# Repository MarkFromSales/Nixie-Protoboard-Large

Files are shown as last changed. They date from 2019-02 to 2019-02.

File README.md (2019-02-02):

# Nixie-Protoboard-Large Board
Protoboard for testing Nixie tube driving software development

I have a bunch of the new-old-stock K155ID1 chips that I found cheap on Amazon and eBay. I've been told NTE still makes the 74141 and found these links,

http://www.nteinc.com/specs/7400to7499/pdf/nte74141.pdf
http://dilp.netcomponents.com/cgi-bin/nteinc.asp?partnumber1=NTE74141

# Nixie Tube Tester Code
Learning to code for the Arduino for a Nixie tube project.
ATmega328 Driving SN74141 Nixie driver chip via pins A, B, C, & D

## Attributions and Thanks
- ATMega328 outside of Arduino Uno - https://dronebotworkshop.com/arduino-uno-atmega328/
- Multi-tasking the Arduino - https://learn.adafruit.com/multi-tasking-the-arduino-part-1?view=all

## Connections
```
ATMega328 Pin 28 (Analog 5 - I2C Clock) to MCP Pin 12
ATMega328 Pin 27 (Analog 4 - I2C Data)  to MCP Pin 13

MCP Pins #15, 16 and 17 are address selection (see below)
MCP Pin  9 to 5V
MCP Pin 10 to GND
MCP Pin 18 to 10K Resistor to 5V (reset pin, active low)
```

## MCP Addresses
```
addr 0 = A2 low,  A1 low,  A0 low  000
addr 1 = A2 low,  A1 low,  A0 high 001
addr 2 = A2 low,  A1 high, A0 low  010
addr 3 = A2 low,  A1 high, A0 high 011
addr 4 = A2 high, A1 low,  A0 low  100
addr 5 = A2 high, A1 low,  A0 high 101
addr 6 = A2 high, A1 high, A0 low  110
addr 7 = A2 high, A1 high, A0 high 111
```

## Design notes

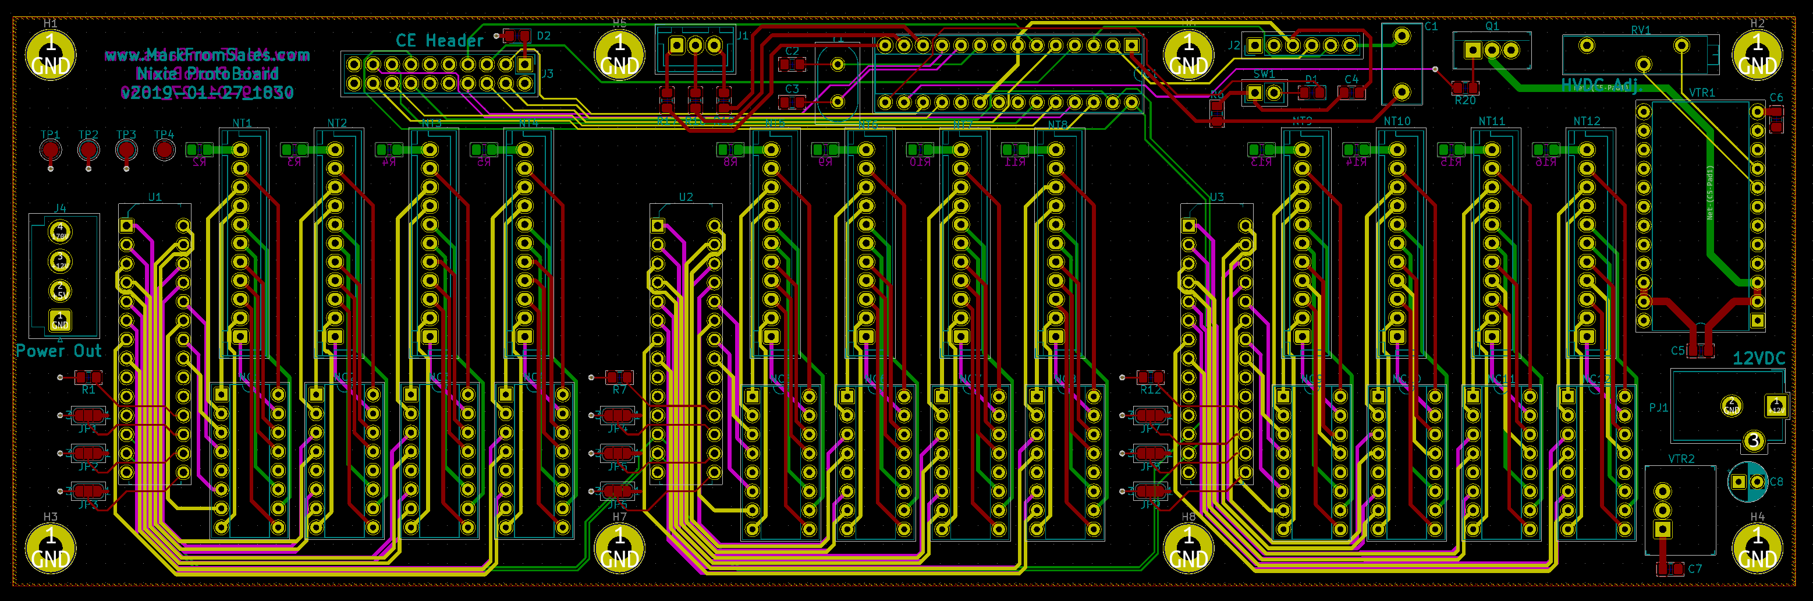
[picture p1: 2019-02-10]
Nixie-Protoboard-Large_PCB_Screenshot.PNG

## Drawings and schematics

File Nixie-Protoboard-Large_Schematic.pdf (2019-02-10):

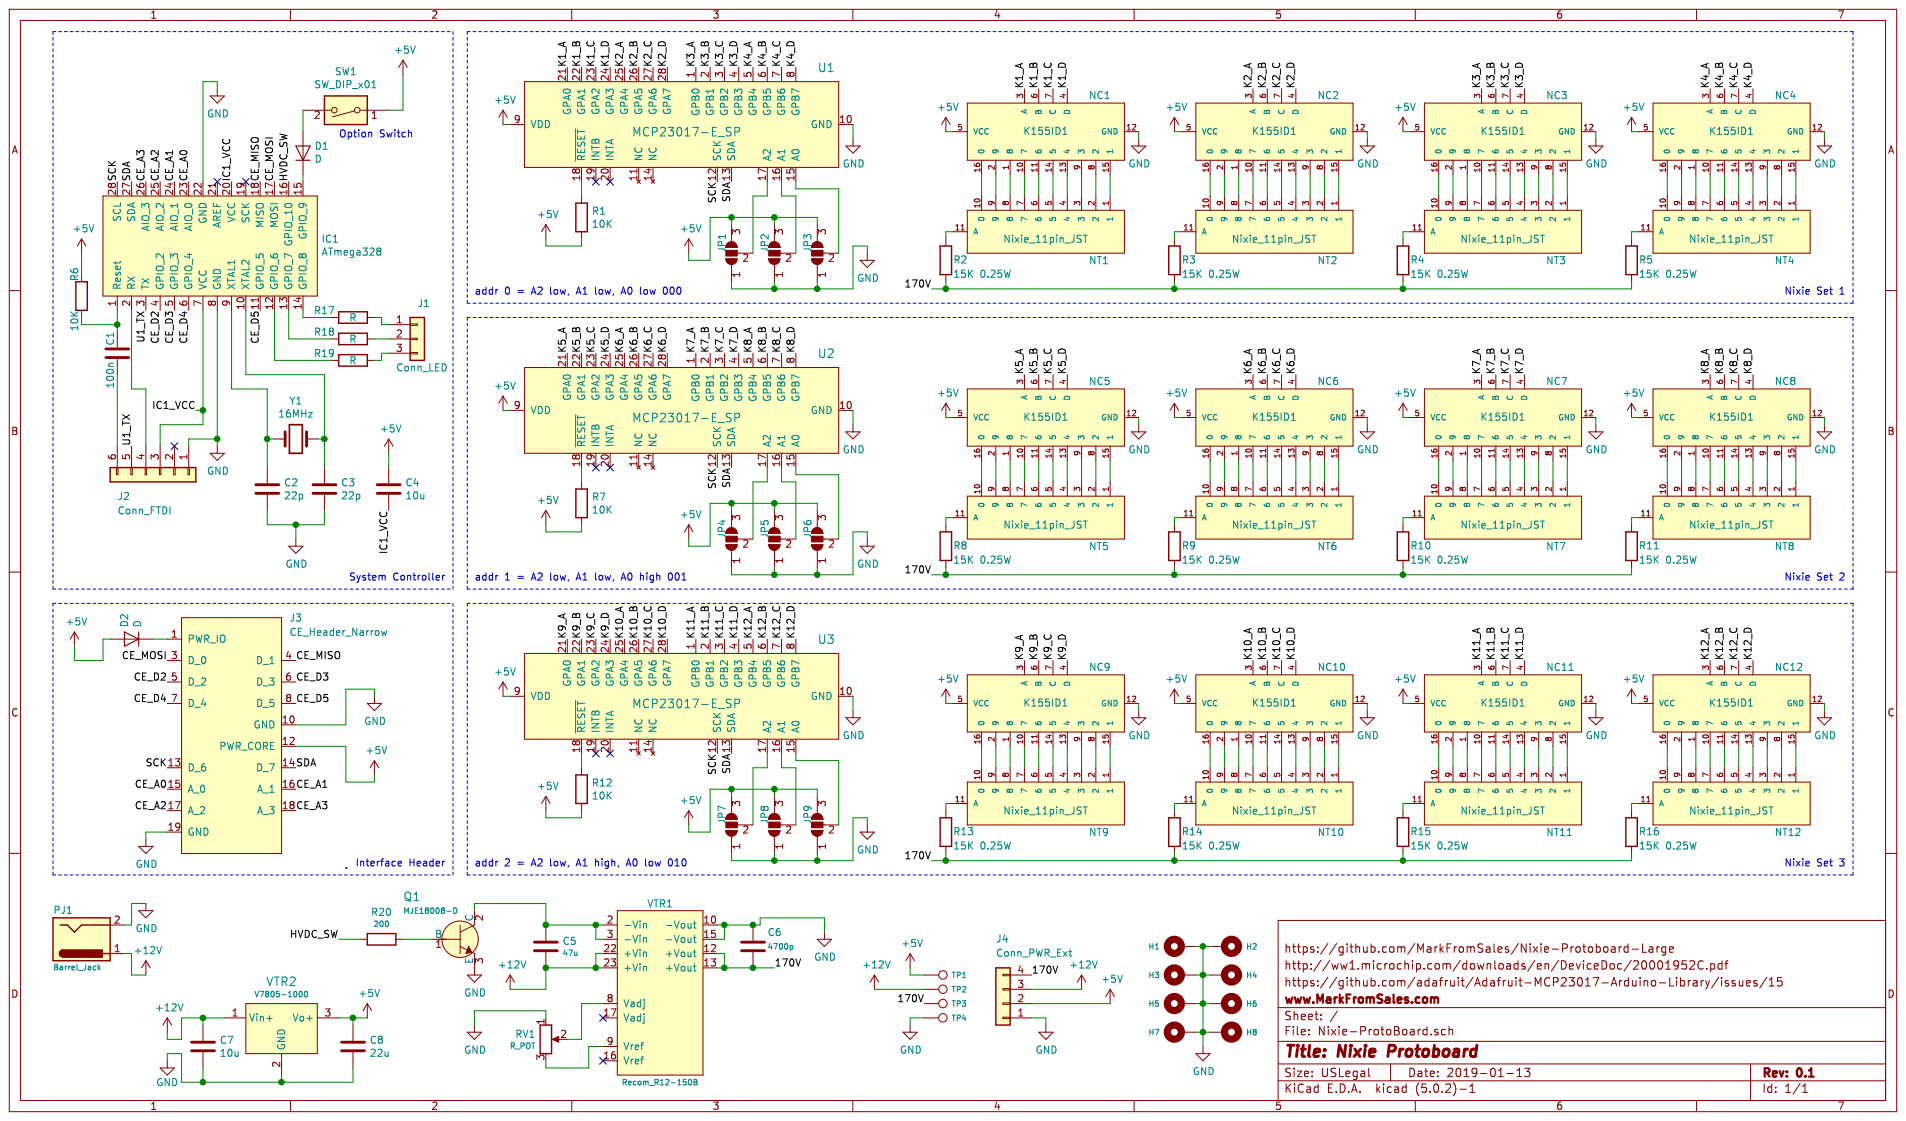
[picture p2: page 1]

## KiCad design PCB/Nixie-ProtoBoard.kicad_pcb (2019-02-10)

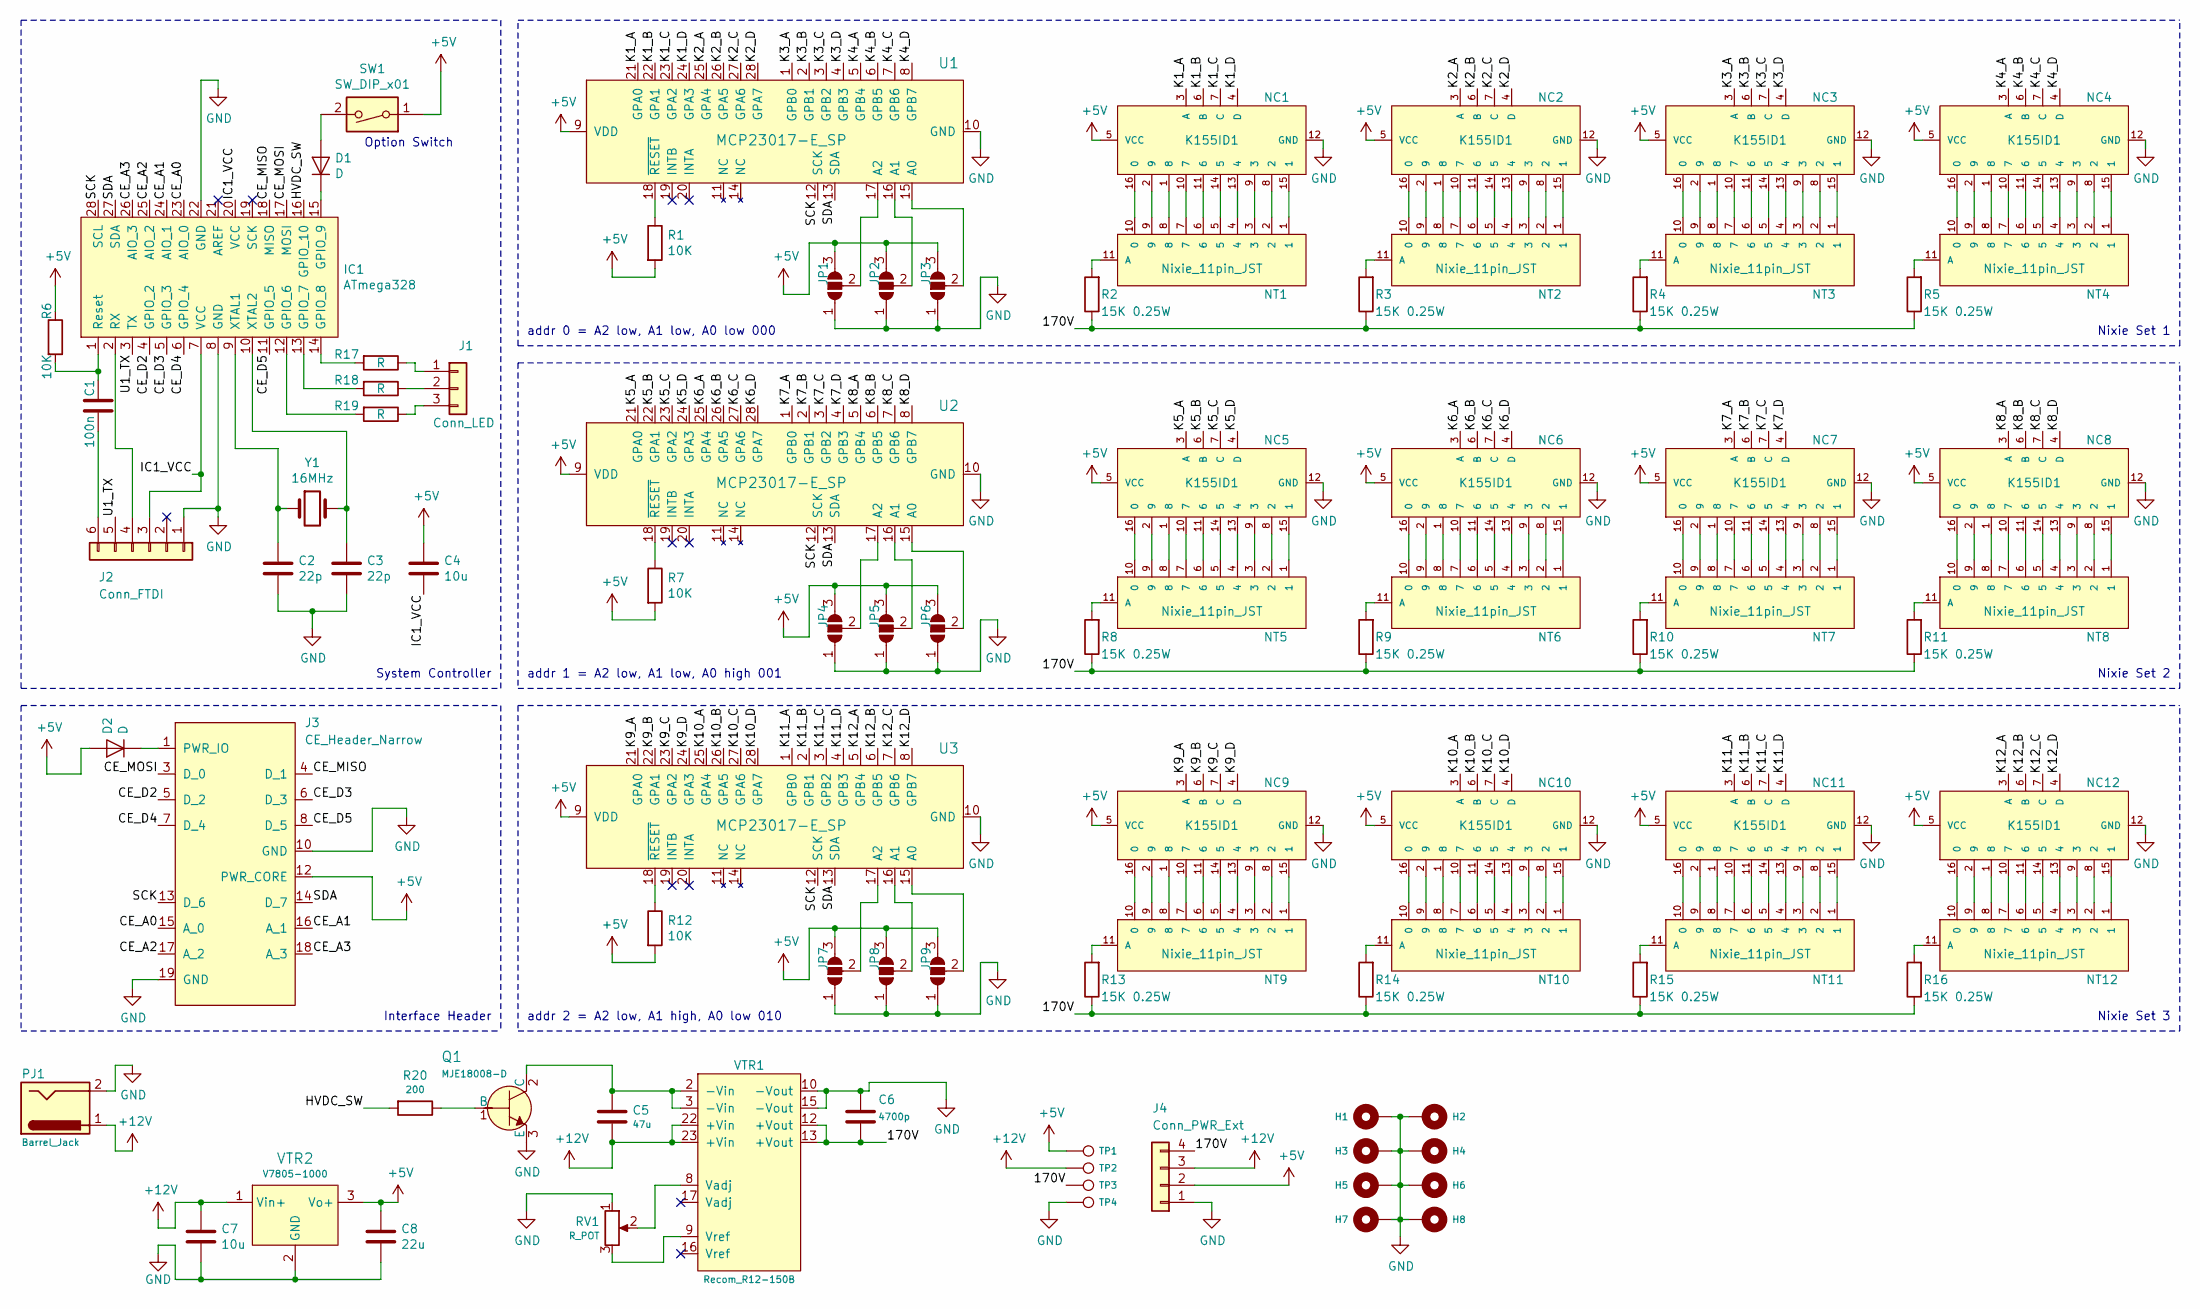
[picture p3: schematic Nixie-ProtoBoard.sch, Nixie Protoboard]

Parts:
C1: 100n; C_Disc_D10.5mm_W5.0mm_P7.50mm
C2, C3: 22p; C_0805_2012Metric_Pad1.15x1.40mm_HandSolder
C4, C7: 10u; C_0805_2012Metric_Pad1.15x1.40mm_HandSolder
C5: 47u; C_0805_2012Metric_Pad1.15x1.40mm_HandSolder
C6: 4700p; C_0805_2012Metric_Pad1.15x1.40mm_HandSolder
C8: 22u; CP_Radial_D5.0mm_P2.50mm
D1, D2: D; D_0805_2012Metric_Pad1.15x1.40mm_HandSolder
H1, H2, H3, H4, H5, H6, H7, H8: MountingHole_Pad; MountingHole_3.2mm_M3_Pad
IC1: ATmega328; DIP-28_W7.62mm_Socket
J1: Conn_LED; JST_XH_B03B-XH-A_1x03_P2.50mm_Vertical
J2: Conn_FTDI; PinHeader_1x06_P2.54mm_Vertical
J3: CE_Header_Narrow; PinHeader_2x10_P2.54mm_Vertical
J4: Conn_PWR_Ext; JST_VH_B4P-VH_1x04_P3.96mm_Vertical
JP1, JP2, JP3, JP4, JP5, JP6, JP7, JP8, JP9: SolderJumper_3_Open; SolderJumper-3_P1.3mm_Open_RoundedPad1.0x1.5mm_NumberLabels
NC1, NC2, NC3, NC4, NC5, NC6, NC7, NC8, NC9, NC10, NC11, NC12: K155ID1; DIP-16_W7.62mm_Socket
NT1, NT2, NT3, NT4, NT5, NT6, NT7, NT8, NT9, NT10, NT11, NT12: Nixie_11pin_JST; JST_XH_B11B-XH-A_1x11_P2.50mm_Vertical
PJ1: Barrel_Jack; BarrelJack_CUI_PJ-102AH_Horizontal
Q1: MJE18008-D; TO-220-3; MPN MJE15030G; Digi-Key_PN MJE15030GOS-ND
R1, R6, R7, R12: 10K; R_0805_2012Metric_Pad1.15x1.40mm_HandSolder
R2, R3, R4, R5, R8, R9, R10, R11, R13, R14, R15, R16: 15K 0.25W; R_0805_2012Metric_Pad1.15x1.40mm_HandSolder
R17, R18, R19: R; R_0805_2012Metric_Pad1.15x1.40mm_HandSolder
R20: 200; R_0805_2012Metric_Pad1.15x1.40mm_HandSolder
RV1: R_POT; Potentiometer_Vishay_43_Horizontal
SW1: SW_DIP_x01; PinHeader_1x02_P2.54mm_Vertical
TP1, TP2, TP3, TP4: TestPoint; TestPoint_Pad_D2.0mm
U1, U2, U3: MCP23017-E_SP; DIP-28_W7.62mm; MPN MCP23017-E/SP; Digi-Key_PN MCP23017-E/SP-ND
VTR1: Recom_R12-150B; DIP-24_W15.24mm
VTR2: V7805-1000; 3-SIP_Module_V7805-1000; MPN V7805-1000; Digi-Key_PN 102-1715-ND
Y1: 16MHz; Resonator-2Pin_W10.0mm_H5.0mm

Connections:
+5V: C4.1, C8.1, D2.2 (A), J3.12 (PWR_CORE), J4.2, JP1.3 (B), JP2.3 (B), JP3.3 (B), JP4.3 (B), JP5.3 (B), JP6.3 (B), JP7.3 (B), JP8.3 (B), JP9.3 (B), NC1.5 (VCC), NC2.5 (VCC), NC3.5 (VCC), NC4.5 (VCC), NC5.5 (VCC), NC6.5 (VCC), NC7.5 (VCC), NC8.5 (VCC), NC9.5 (VCC), NC10.5 (VCC), NC11.5 (VCC), NC12.5 (VCC), R1.2, R6.1, R7.2, R12.2, SW1.1, TP1.1, U1.9 (VDD), U2.9 (VDD), U3.9 (VDD), VTR2.3 (Vo+)
+12V: C5.2, C7.1, J4.3, PJ1.1, TP2.1, VTR1.22 (+Vin), VTR1.23 (+Vin), VTR2.1 (Vin+)
/170V: C6.2, J4.4, R2.1, R3.1, R4.1, R5.1, R8.1, R9.1, R10.1, R11.1, R13.1, R14.1, R15.1, R16.1, TP3.1, VTR1.12 (+Vout), VTR1.13 (+Vout)
/CE_A0: IC1.23 (AIO_0), J3.15 (A_0)
/CE_A1: IC1.24 (AIO_1), J3.16 (A_1)
/CE_A2: IC1.25 (AIO_2), J3.17 (A_2)
/CE_A3: IC1.26 (AIO_3), J3.18 (A_3)
/CE_D2: IC1.4 (GPIO_2), J3.5 (D_2)
/CE_D3: IC1.5 (GPIO_3), J3.6 (D_3)
/CE_D4: IC1.6 (GPIO_4), J3.7 (D_4)
/CE_D5: IC1.11 (GPIO_5), J3.8 (D_5)
/CE_MISO: IC1.18 (MISO), J3.4 (D_1)
/CE_MOSI: IC1.17 (MOSI), J3.3 (D_0)
/HVDC_SW: IC1.16 (GPIO_10), R20.2
/IC1_VCC: C4.2, IC1.7 (VCC), IC1.20 (VCC), J2.3
/K1_A: NC1.3 (A), U1.21 (GPA0)
/K1_B: NC1.6 (B), U1.22 (GPA1)
/K1_C: NC1.7 (C), U1.23 (GPA2)
/K1_D: NC1.4 (D), U1.24 (GPA3)
/K2_A: NC2.3 (A), U1.25 (GPA4)
/K2_B: NC2.6 (B), U1.26 (GPA5)
/K2_C: NC2.7 (C), U1.27 (GPA6)
/K2_D: NC2.4 (D), U1.28 (GPA7)
/K3_A: NC3.3 (A), U1.1 (GPB0)
/K3_B: NC3.6 (B), U1.2 (GPB1)
/K3_C: NC3.7 (C), U1.3 (GPB2)
/K3_D: NC3.4 (D), U1.4 (GPB3)
/K4_A: NC4.3 (A), U1.5 (GPB4)
/K4_B: NC4.6 (B), U1.6 (GPB5)
/K4_C: NC4.7 (C), U1.7 (GPB6)
/K4_D: NC4.4 (D), U1.8 (GPB7)
/K5_A: NC5.3 (A), U2.21 (GPA0)
/K5_B: NC5.6 (B), U2.22 (GPA1)
/K5_C: NC5.7 (C), U2.23 (GPA2)
/K5_D: NC5.4 (D), U2.24 (GPA3)
/K6_A: NC6.3 (A), U2.25 (GPA4)
/K6_B: NC6.6 (B), U2.26 (GPA5)
/K6_C: NC6.7 (C), U2.27 (GPA6)
/K6_D: NC6.4 (D), U2.28 (GPA7)
/K7_A: NC7.3 (A), U2.1 (GPB0)
/K7_B: NC7.6 (B), U2.2 (GPB1)
/K7_C: NC7.7 (C), U2.3 (GPB2)
/K7_D: NC7.4 (D), U2.4 (GPB3)
/K8_A: NC8.3 (A), U2.5 (GPB4)
/K8_B: NC8.6 (B), U2.6 (GPB5)
/K8_C: NC8.7 (C), U2.7 (GPB6)
/K8_D: NC8.4 (D), U2.8 (GPB7)
/K9_A: NC9.3 (A), U3.21 (GPA0)
/K9_B: NC9.6 (B), U3.22 (GPA1)
/K9_C: NC9.7 (C), U3.23 (GPA2)
/K9_D: NC9.4 (D), U3.24 (GPA3)
/K10_A: NC10.3 (A), U3.25 (GPA4)
/K10_B: NC10.6 (B), U3.26 (GPA5)
/K10_C: NC10.7 (C), U3.27 (GPA6)
/K10_D: NC10.4 (D), U3.28 (GPA7)
/K11_A: NC11.3 (A), U3.1 (GPB0)
/K11_B: NC11.6 (B), U3.2 (GPB1)
/K11_C: NC11.7 (C), U3.3 (GPB2)
/K11_D: NC11.4 (D), U3.4 (GPB3)
/K12_A: NC12.3 (A), U3.5 (GPB4)
/K12_B: NC12.6 (B), U3.6 (GPB5)
/K12_C: NC12.7 (C), U3.7 (GPB6)
/K12_D: NC12.4 (D), U3.8 (GPB7)
/SCK: IC1.28 (SCL), J3.13 (D_6), U1.12 (SCK), U2.12 (SCK), U3.12 (SCK)
/SDA: IC1.27 (SDA), J3.14 (D_7), U1.13 (SDA), U2.13 (SDA), U3.13 (SDA)
/U1_TX: IC1.3 (TX), J2.5
GND: C2.2, C3.2, C6.1, C7.2, C8.2, H1.1, H2.1, H3.1, H4.1, H5.1, H6.1, H7.1, H8.1, IC1.8 (GND), IC1.22 (GND), J2.1, J3.10 (GND), J3.19 (GND), J4.1, JP1.1 (A), JP2.1 (A), JP3.1 (A), JP4.1 (A), JP5.1 (A), JP6.1 (A), JP7.1 (A), JP8.1 (A), JP9.1 (A), NC1.12 (GND), NC2.12 (GND), NC3.12 (GND), NC4.12 (GND), NC5.12 (GND), NC6.12 (GND), NC7.12 (GND), NC8.12 (GND), NC9.12 (GND), NC10.12 (GND), NC11.12 (GND), NC12.12 (GND), PJ1.2, Q1.3 (E), RV1.1, TP4.1, U1.10 (GND), U2.10 (GND), U3.10 (GND), VTR1.10 (-Vout), VTR1.15 (-Vout), VTR2.2 (GND)
unnamed: C1.1, IC1.1 (Reset), R6.2
unnamed: C1.2, J2.6
unnamed: C2.1, IC1.9 (XTAL1), Y1.1
unnamed: C3.1, IC1.10 (XTAL2), Y1.2
unnamed: C5.1, Q1.2 (C), VTR1.2 (-Vin), VTR1.3 (-Vin)
unnamed: D1.1 (K), IC1.15 (GPIO_9)
unnamed: D1.2 (A), SW1.2
unnamed: D2.1 (K), J3.1 (PWR_IO)
unnamed: IC1.2 (RX), J2.4
unnamed: IC1.12 (GPIO_6), R19.2
unnamed: IC1.13 (GPIO_7), R18.2
unnamed: IC1.14 (GPIO_8), R17.2
unnamed: J1.1, R17.1
unnamed: J1.2, R18.1
unnamed: J1.3, R19.1
unnamed: JP1.2 (C), U1.17 (A2)
unnamed: JP2.2 (C), U1.16 (A1)
unnamed: JP3.2 (C), U1.15 (A0)
unnamed: JP4.2 (C), U2.17 (A2)
unnamed: JP5.2 (C), U2.16 (A1)
unnamed: JP6.2 (C), U2.15 (A0)
unnamed: JP7.2 (C), U3.17 (A2)
unnamed: JP8.2 (C), U3.16 (A1)
unnamed: JP9.2 (C), U3.15 (A0)
unnamed: NC1.1 (8), NT1.8
unnamed: NC1.2 (9), NT1.9
unnamed: NC1.8 (2), NT1.2
unnamed: NC1.9 (3), NT1.3
unnamed: NC1.10 (7), NT1.7
unnamed: NC1.11 (6), NT1.6
unnamed: NC1.13 (4), NT1.4
unnamed: NC1.14 (5), NT1.5
unnamed: NC1.15 (1), NT1.1
unnamed: NC1.16 (0), NT1.10 (0)
unnamed: NC2.1 (8), NT2.8
unnamed: NC2.2 (9), NT2.9
unnamed: NC2.8 (2), NT2.2
unnamed: NC2.9 (3), NT2.3
unnamed: NC2.10 (7), NT2.7
unnamed: NC2.11 (6), NT2.6
unnamed: NC2.13 (4), NT2.4
unnamed: NC2.14 (5), NT2.5
unnamed: NC2.15 (1), NT2.1
unnamed: NC2.16 (0), NT2.10 (0)
unnamed: NC3.1 (8), NT3.8
unnamed: NC3.2 (9), NT3.9
unnamed: NC3.8 (2), NT3.2
unnamed: NC3.9 (3), NT3.3
unnamed: NC3.10 (7), NT3.7
unnamed: NC3.11 (6), NT3.6
unnamed: NC3.13 (4), NT3.4
unnamed: NC3.14 (5), NT3.5
unnamed: NC3.15 (1), NT3.1
unnamed: NC3.16 (0), NT3.10 (0)
unnamed: NC4.1 (8), NT4.8
unnamed: NC4.2 (9), NT4.9
unnamed: NC4.8 (2), NT4.2
unnamed: NC4.9 (3), NT4.3
unnamed: NC4.10 (7), NT4.7
unnamed: NC4.11 (6), NT4.6
unnamed: NC4.13 (4), NT4.4
unnamed: NC4.14 (5), NT4.5
unnamed: NC4.15 (1), NT4.1
unnamed: NC4.16 (0), NT4.10 (0)
unnamed: NC5.1 (8), NT5.8
unnamed: NC5.2 (9), NT5.9
unnamed: NC5.8 (2), NT5.2
unnamed: NC5.9 (3), NT5.3
unnamed: NC5.10 (7), NT5.7
unnamed: NC5.11 (6), NT5.6
unnamed: NC5.13 (4), NT5.4
unnamed: NC5.14 (5), NT5.5
unnamed: NC5.15 (1), NT5.1
unnamed: NC5.16 (0), NT5.10 (0)
unnamed: NC6.1 (8), NT6.8
unnamed: NC6.2 (9), NT6.9
unnamed: NC6.8 (2), NT6.2
unnamed: NC6.9 (3), NT6.3
unnamed: NC6.10 (7), NT6.7
unnamed: NC6.11 (6), NT6.6
unnamed: NC6.13 (4), NT6.4
unnamed: NC6.14 (5), NT6.5
unnamed: NC6.15 (1), NT6.1
unnamed: NC6.16 (0), NT6.10 (0)
unnamed: NC7.1 (8), NT7.8
unnamed: NC7.2 (9), NT7.9
unnamed: NC7.8 (2), NT7.2
unnamed: NC7.9 (3), NT7.3
unnamed: NC7.10 (7), NT7.7
unnamed: NC7.11 (6), NT7.6
unnamed: NC7.13 (4), NT7.4
unnamed: NC7.14 (5), NT7.5
unnamed: NC7.15 (1), NT7.1
unnamed: NC7.16 (0), NT7.10 (0)
unnamed: NC8.1 (8), NT8.8
unnamed: NC8.2 (9), NT8.9
unnamed: NC8.8 (2), NT8.2
unnamed: NC8.9 (3), NT8.3
unnamed: NC8.10 (7), NT8.7
unnamed: NC8.11 (6), NT8.6
unnamed: NC8.13 (4), NT8.4
unnamed: NC8.14 (5), NT8.5
unnamed: NC8.15 (1), NT8.1
unnamed: NC8.16 (0), NT8.10 (0)
unnamed: NC9.1 (8), NT9.8
unnamed: NC9.2 (9), NT9.9
unnamed: NC9.8 (2), NT9.2
unnamed: NC9.9 (3), NT9.3
unnamed: NC9.10 (7), NT9.7
unnamed: NC9.11 (6), NT9.6
unnamed: NC9.13 (4), NT9.4
unnamed: NC9.14 (5), NT9.5
unnamed: NC9.15 (1), NT9.1
unnamed: NC9.16 (0), NT9.10 (0)
unnamed: NC10.1 (8), NT10.8
unnamed: NC10.2 (9), NT10.9
unnamed: NC10.8 (2), NT10.2
unnamed: NC10.9 (3), NT10.3
unnamed: NC10.10 (7), NT10.7
unnamed: NC10.11 (6), NT10.6
unnamed: NC10.13 (4), NT10.4
unnamed: NC10.14 (5), NT10.5
unnamed: NC10.15 (1), NT10.1
unnamed: NC10.16 (0), NT10.10 (0)
unnamed: NC11.1 (8), NT11.8
unnamed: NC11.2 (9), NT11.9
unnamed: NC11.8 (2), NT11.2
unnamed: NC11.9 (3), NT11.3
unnamed: NC11.10 (7), NT11.7
unnamed: NC11.11 (6), NT11.6
unnamed: NC11.13 (4), NT11.4
unnamed: NC11.14 (5), NT11.5
unnamed: NC11.15 (1), NT11.1
unnamed: NC11.16 (0), NT11.10 (0)
unnamed: NC12.1 (8), NT12.8
unnamed: NC12.2 (9), NT12.9
unnamed: NC12.8 (2), NT12.2
unnamed: NC12.9 (3), NT12.3
unnamed: NC12.10 (7), NT12.7
unnamed: NC12.11 (6), NT12.6
unnamed: NC12.13 (4), NT12.4
unnamed: NC12.14 (5), NT12.5
unnamed: NC12.15 (1), NT12.1
unnamed: NC12.16 (0), NT12.10 (0)
unnamed: NT1.11 (A), R2.2
unnamed: NT2.11 (A), R3.2
unnamed: NT3.11 (A), R4.2
unnamed: NT4.11 (A), R5.2
unnamed: NT5.11 (A), R8.2
unnamed: NT6.11 (A), R9.2
unnamed: NT7.11 (A), R10.2
unnamed: NT8.11 (A), R11.2
unnamed: NT9.11 (A), R13.2
unnamed: NT10.11 (A), R14.2
unnamed: NT11.11 (A), R15.2
unnamed: NT12.11 (A), R16.2
unnamed: Q1.1 (B), R20.1
unnamed: R1.1, U1.18 (~RESET)
unnamed: R7.1, U2.18 (~RESET)
unnamed: R12.1, U3.18 (~RESET)
unnamed: RV1.2, VTR1.8 (Vadj)
unnamed: RV1.3, VTR1.9 (Vref)

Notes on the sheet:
Nixie Set 1
Nixie Set 2
System Controller
Option Switch
Nixie Set 3
addr 0 = A2 low, A1 low, A0 low 000
addr 1 = A2 low, A1 low, A0 high 001
addr 2 = A2 low, A1 high, A0 low 010
Interface Header

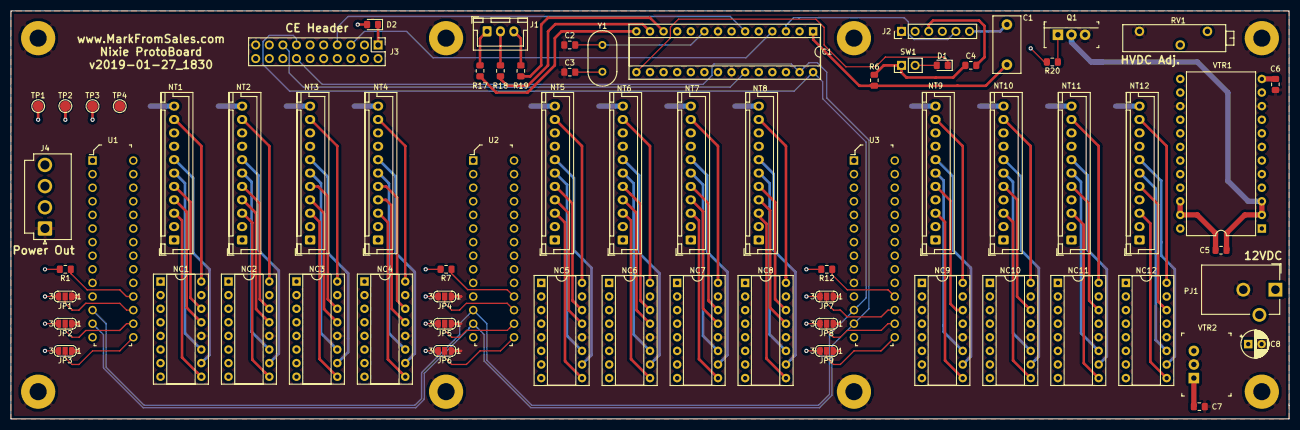
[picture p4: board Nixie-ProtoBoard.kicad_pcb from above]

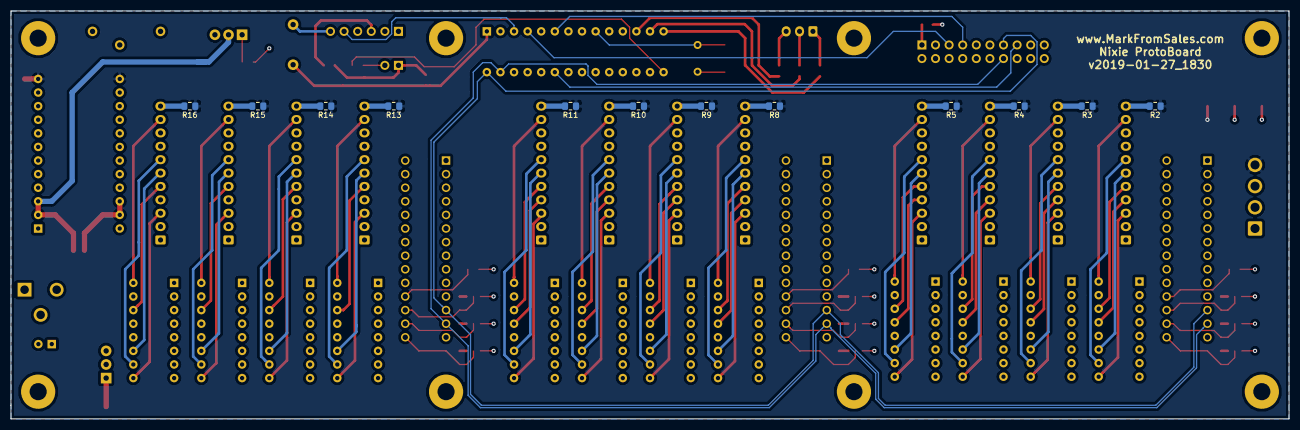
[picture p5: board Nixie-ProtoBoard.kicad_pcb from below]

Board: 4 copper layers, 238.8 x 76.2 mm, 90 parts (12 on the bottom side), 229 nets.

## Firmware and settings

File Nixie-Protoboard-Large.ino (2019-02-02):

/* 
https://github.com/MarkFromSales/Nixie-Protoboard-Large
More information in the README.MD
*/

// Setup MCP GPIO expanders
#include "Adafruit_MCP23017.h"
Adafruit_MCP23017 mcp1;
Adafruit_MCP23017 mcp2;
#define addr1 0  // 0 = A2 low , A1 low , A0 low
#define addr2 7  // 7 = A2 high, A1 high, A0 high

// Setup Tube Variables
int nxeBL = 2;   // Nixie tube backlight control pin
int pinSW = 3;   // Enable switch GPIO 3, pin 5
int valSW = 0;   // Variable for Enable switch pin value
int pinCT = 16;  // How many pins in the MCPs to enable +1
int psuSW = 5;   // Shutdown for HVDC PSU GPIO 5, pin 11

// Function to set all the MCP GPIO pins to HIGH, shutting off the Nixies
void NixiesOff (){
  for (int thisPin = 0; thisPin < pinCT; thisPin++) {
      mcp1.digitalWrite(thisPin, HIGH);
      mcp2.digitalWrite(thisPin, HIGH);
  }
};

// Setup LCD Display
#include <LiquidCrystal.h>
LiquidCrystal lcd(7, 8, 9, 10, 11, 12);  // Initialize the library with the numbers of the interface pins
int pinBS = A3; // Analog  pin 3 (D17) to wiper of pot
int pinBL = 6;  // Digital pin 6 (PWM) to LCD backlight VCC
int valBL = 0;  // Variable to store the read value

// Setup Adafruit INA219 current sensor
#include <Adafruit_INA219.h>
Adafruit_INA219 ina219_A;
int power_mW;

  
// Tube state machine
int tubeMatrix[9][4] = {
  { 0, 0, 0, 0 },      // Row 0: Not used, loops will start with 1
  { 0, 1, 2, 3 },      // Row 1: Tube 1
  { 4, 5, 6, 7 },      // Row 2: Tube 2
  { 8, 9, 10, 11 },    // Row 3: Tube 3
  { 12, 13, 14, 15 },  // Row 4: Tube 4
  { 0, 1, 2, 3 },      // Row 5: Tube 5
  { 4, 5, 6, 7 },      // Row 6: Tube 6
  { 8, 9, 10, 11 },    // Row 7: Tube 7
  { 12, 13, 14, 15 }   // Row 8: Tube 8
};

class Rotator {
  // Class member values
  int ledPin;     // LED state pin
  int tubeID;     // Sets which tube to update
  long OnTime;    // milliseconds of on-time
  long OffTime;   // milliseconds of off-time
  int tubeVal;    // Sets the value of the tube
  int ledState;   // Maintains the current state
  unsigned long previousMillis;   // will store last time LED was updated

  public:
  Rotator(int tube, long on, long off, int value) {
    ledPin = 13;
    pinMode(ledPin, OUTPUT);
    tubeID = tube;
    OnTime = on;
    OffTime = off;
    tubeVal = value;
    ledState = LOW;
    previousMillis = 0;
  }

  void Update(){
    // Check to see if it's time to change the state of the LED
    unsigned long currentMillis = millis();

    if((ledState == HIGH) && (currentMillis - previousMillis >= OnTime)) {
      ledState = LOW;                  // Turn LED off
      NixiesOff();                     // Turn nixie tubes off
      previousMillis = currentMillis;  // Remember the time
      digitalWrite(ledPin, ledState);  // Update the actual LED
      Serial.print("Nixies_OFF  TubeID: ");
      Serial.print(tubeID);
      Serial.print("  PreviousMillis: ");
      Serial.print(previousMillis);
      Serial.print("  CurrentMillis: ");
      Serial.println(currentMillis);
    }

    else if ((ledState == LOW) && (currentMillis - previousMillis >= OffTime)) {
      ledState = HIGH;                  // Turn LED on
      previousMillis = currentMillis;   // Remember the time
      digitalWrite(ledPin, ledState);    // Update the actual LED
      Serial.print("Nixies_ON   TubeID: ");
      Serial.print(tubeID);
      Serial.print("  PreviousMillis: ");
      Serial.print(previousMillis);
      Serial.print("  CurrentMillis: ");
      Serial.println(currentMillis);

      // Setting the value of the tube, 1st set of 4 tubes on MCP1
      if (tubeID > 0 && tubeID < 5) {
        mcp1.digitalWrite(tubeMatrix[tubeID][3], (tubeVal & 0x08) >> 3);
        mcp1.digitalWrite(tubeMatrix[tubeID][2], (tubeVal & 0x04) >> 2);
        mcp1.digitalWrite(tubeMatrix[tubeID][1], (tubeVal & 0x02) >> 1);
        mcp1.digitalWrite(tubeMatrix[tubeID][0], tubeVal & 0x01);
      }

      // Setting the value of the tube, 2nd set of 4 tubes on MCP2
      else {
        mcp2.digitalWrite(tubeMatrix[tubeID][3], (tubeVal & 0x08) >> 3);
        mcp2.digitalWrite(tubeMatrix[tubeID][2], (tubeVal & 0x04) >> 2);
        mcp2.digitalWrite(tubeMatrix[tubeID][1], (tubeVal & 0x02) >> 1);
        mcp2.digitalWrite(tubeMatrix[tubeID][0], tubeVal & 0x01);
      }
    }
  }
};

int timeOn = 5000;   // Tube On duration X
int timeOff = 5000;  // Tube Off duration Y

Rotator tube1(1, timeOn, timeOff, 1);  // Tube #, on for X, off for Y, display number
Rotator tube2(2, timeOn, timeOff, 2);
Rotator tube3(3, timeOn, timeOff, 3);
Rotator tube4(4, timeOn, timeOff, 4);
Rotator tube5(5, timeOn, timeOff, 5);
Rotator tube6(6, timeOn, timeOff, 6);
Rotator tube7(7, timeOn, timeOff, 7);
Rotator tube8(8, timeOn, timeOff, 8);

void setup() {
  Serial.begin(9600);
  Serial.println();
  Serial.println("Setup Start");
  mcp1.begin(addr1);
  mcp2.begin(addr2);

  // Set MCP Nixie Tube pins to OUTPUT
  for (int thisPin = 0; thisPin < pinCT; thisPin++) {
    mcp1.pinMode(thisPin, OUTPUT);
    mcp2.pinMode(thisPin, OUTPUT);
  }

  pinMode(nxeBL, OUTPUT);
  pinMode(pinSW, INPUT);
  pinMode(psuSW, OUTPUT);

  // set up the LCD's number of rows and columns: 
  pinMode(pinBS, INPUT);
  pinMode(pinBL, OUTPUT);
  lcd.begin(16, 2);

  // Print a message to the LCD as an initialization test
  lcd.setCursor(0,0);
  lcd.print("LCD 16x2 Display");
  lcd.setCursor(0,1);
  lcd.print("Mono Color LCD  ");
  lcd.clear();
  
  // Adafruit INA219 Current Sensor
  ina219_A.begin();  // Initialize first board (default address 0x40)
  uint32_t currentFrequency;
  
  Serial.println("Setup End");

}

void loop() {
  valBL = analogRead(pinBS);       // Read the wiper from the LCD brightness pot
  analogWrite(pinBL, valBL / 4);   // Turn on LCD backlight
  valSW = digitalRead(pinSW);      // Check the state of the Nixie enable switch
  
  // Adafruit INA219
  //shuntvoltage = ina219_A.getShuntVoltage_mV();
  //busvoltage = ina219_A.getBusVoltage_V();
  //current_mA = ina219_A.getCurrent_mA();
  power_mW = ina219_A.getPower_mW();
  //loadvoltage = busvoltage + (shuntvoltage / 1000);
  
  // Check to see if user switch is on (otherwise Else)
  if (valSW == 1) {
    lcd.setCursor(0,0);
    lcd.print("Sw ON           ");
    lcd.setCursor(9,0);
    lcd.print(millis() / 1000);
    lcd.setCursor(0,1);
    //lcd.print("Nixies Flashing?");
    lcd.print(power_mW / 1000);
    lcd.setCursor(7,1);
    lcd.print("W");
    
    digitalWrite(nxeBL, HIGH);     // Turn on tube backlight LED
    analogWrite(psuSW, 160);       // Turn on tube power supply (relay) 0-255, 165 is about 3.3V
    
    tube1.Update();
    tube2.Update();
    tube3.Update();
    tube4.Update();
    tube5.Update();
    tube6.Update();
    tube7.Update();
    tube8.Update();
  }
  else {
    lcd.setCursor(0,0);
    lcd.print("Sw OFF          ");
    lcd.setCursor(9,0);
    lcd.print(millis() / 1000);
    lcd.setCursor(0,1);
    //lcd.print("Nixies Off?     ");
    lcd.print(power_mW / 1000);
    lcd.setCursor(7,1);
    lcd.print("W");
    
    digitalWrite(nxeBL, LOW);     // Turn off tube backlight LED
    analogWrite(psuSW, 0);        // Turn off tube power supply (relay)

    NixiesOff();
  }
}

//EOF

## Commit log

2019-02-02 Initial Upload
    [Nixie-ProtoBoard.kicad_pcb, Nixie-ProtoBoard.sch]
2019-02-02 Arduino code
2019-02-10 Minor updates
    [Nixie-ProtoBoard-B.Cu.gbr, Nixie-ProtoBoard-B.Mask.gbr, Nixie-ProtoBoard-B.Paste.gbr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]
2019-02-13 Updated structure
    [Nixie-ProtoBoard-B.Cu.gbr, Nixie-ProtoBoard-B.Mask.gbr, Nixie-ProtoBoard-B.Paste.gbr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]
